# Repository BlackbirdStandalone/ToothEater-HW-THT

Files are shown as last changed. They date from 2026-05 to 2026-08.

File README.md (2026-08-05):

# ToothEater-HW-THT

This repository contains the hardware design of the Honda Blackbird v1.1 Tooth Eater Module - (Through hole version). This through hole version is intended for the DIY'er for easier construction. This PCB is a simple 2 layer design, measuring 44mm x 44mm for insertion into the Hammond 1551R case.<br /><br />
This hardware is designed to work with the latest firmware version (v1.x) contained in the firmware respository. I.e. <i>'ToothEater_v1.2.hex'.</i><br />
<br />
Shown below are blank boards as received by PCBWay. This is a small unit slightly larger than a matchbox, shown in the 2" x 2" case.

<table border="1">
<tr>

<td align="center" valign="center">
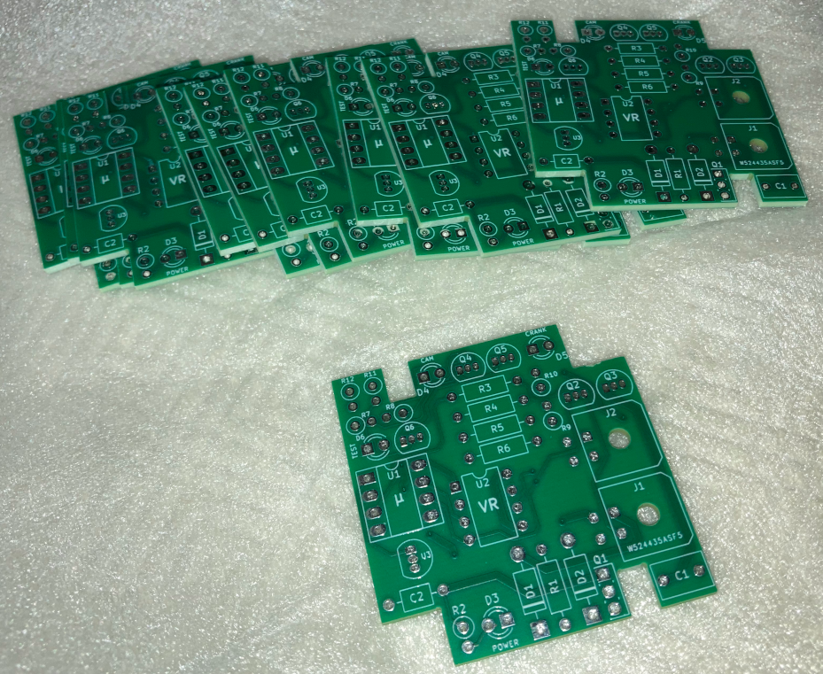
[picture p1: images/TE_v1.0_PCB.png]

</td>

<td>
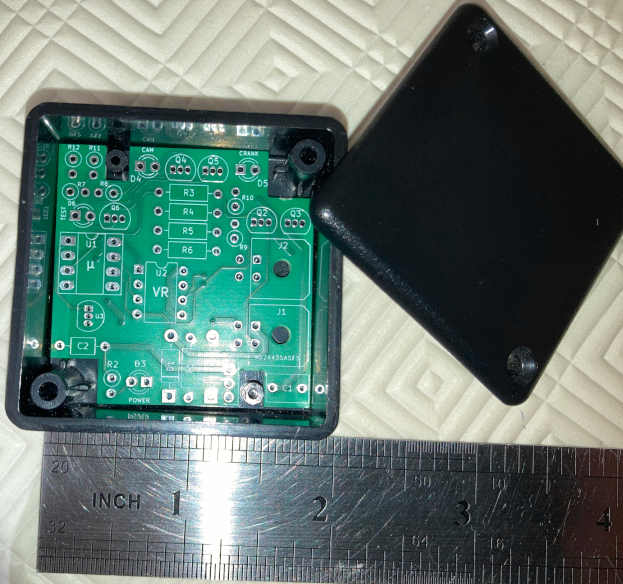
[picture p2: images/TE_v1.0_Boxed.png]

</td>

</tr>
</table>

<br />

A zoomed picture of the board is shown below. The full bill of materials can be found in the 'BOM' directory, however the table below will quickly identify the components. This table reflects the BOM for PCB v1.1.

<table border="3">
<tr>
<td align="center" valign="center"><b><u>Component</u></b></td>
<td align="center" valign="center"><b><u>Value</u></b></td>
</tr>

<tr>
<td align="center" valign="center">U1</td>
<td align="center" valign="center">atTiny85 microcontroller</td>
</tr>

<tr>
<td align="center" valign="center">U2</td>
<td align="center" valign="center">VR conditioner plug-in module (speeduino compatible)</td>
</tr>

<tr>
<td align="center" valign="center">U3</td>
<td align="center" valign="center">MCP100 reset chip</td>
</tr>

<tr>
<td align="center" valign="center">Q1</td>
<td align="center" valign="center">BD681</td>
</tr>

<tr>
<td align="center" valign="center">D1</td>
<td align="center" valign="center">1N4004</td>
</tr>

<tr>
<td align="center" valign="center">D2</td>
<td align="center" valign="center">6.2v zener</td>
</tr>

<tr>
<td align="center" valign="center">C1, C2</td>
<td align="center" valign="center">100n</td>
</tr>

<tr>
<td align="center" valign="center">R1</td>
<td align="center" valign="center">1K5</td>
</tr>

<tr>
<td align="center" valign="center">R2</td>
<td align="center" valign="center">470</td>
</tr>

<tr>
<td align="center" valign="center">R3,R5</td>
<td align="center" valign="center">10K</td>
</tr>

<tr>
<td align="center" valign="center">R4,R6</td>
<td align="center" valign="center">1K</td>
</tr>

<tr>
<td align="center" valign="center">R7,R9</td>
<td align="center" valign="center">47K</td>
</tr>

<tr>
<td align="center" valign="center">R11</td>
<td align="center" valign="center">4K7</td>
</tr>

<tr>
<td align="center" valign="center">R8,R10,R12</td>
<td align="center" valign="center">330</td>
</tr>

<tr>
<td align="center" valign="center">Q2,Q3,Q4,Q5,Q6</td>
<td align="center" valign="center">BC546B</td>
</tr>

<tr>
<td align="center" valign="center">D3</td>
<td align="center" valign="center">Power Led - Red (standard 3mm spacing)</td>
</tr>

<tr>
<td align="center" valign="center">D4,D5</td>
<td align="center" valign="center">Crank and cam Leds - Yellow (standard 3mm spacing)</td>
</tr>

<tr>
<td align="center" valign="center">J1,J2</td>
<td align="center" valign="center">Molex Micro-Fit 3.0 43045 </td>
</tr>

</table>

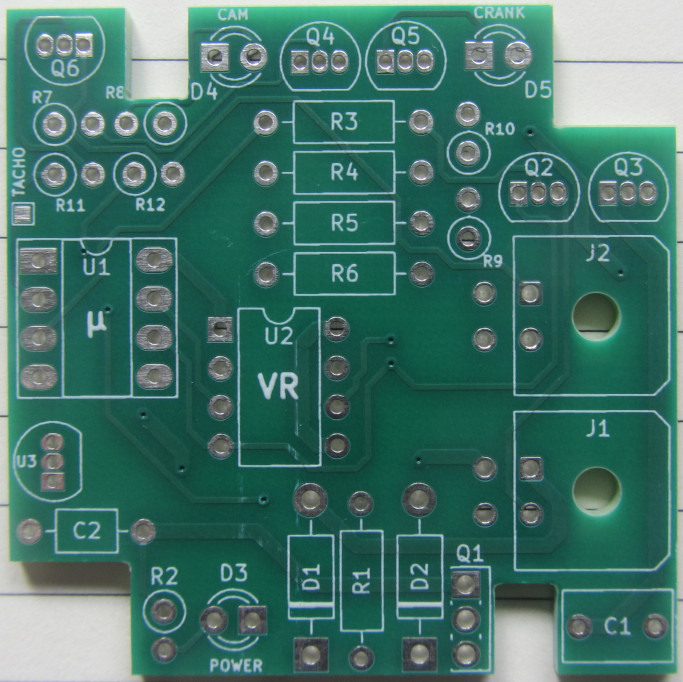
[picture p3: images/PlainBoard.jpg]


<br /><br />
The board is shown below with the components assembled.
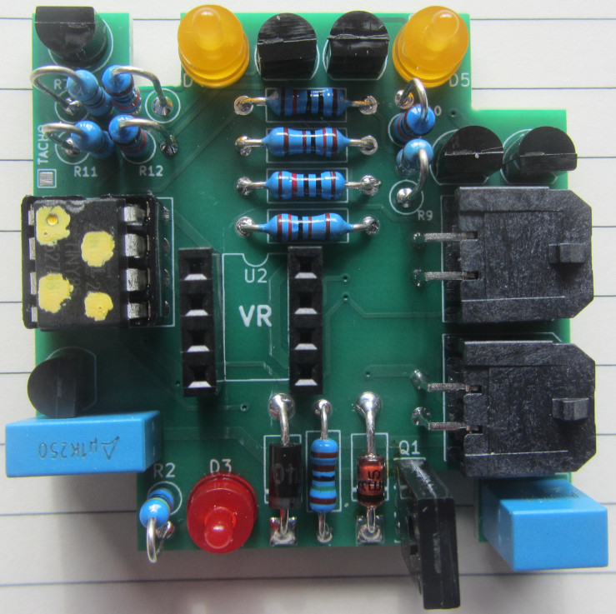
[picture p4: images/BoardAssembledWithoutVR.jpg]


<br />

<table border="1">

The following illustrates different views of the v1.1 assembled board (without the VR mini-board installed).<br />

<tr>
<td align="center" valign="center">
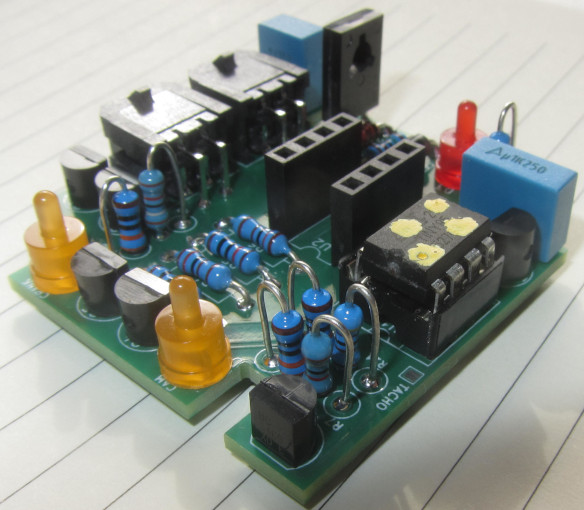
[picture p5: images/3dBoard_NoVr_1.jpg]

</td>
<td>
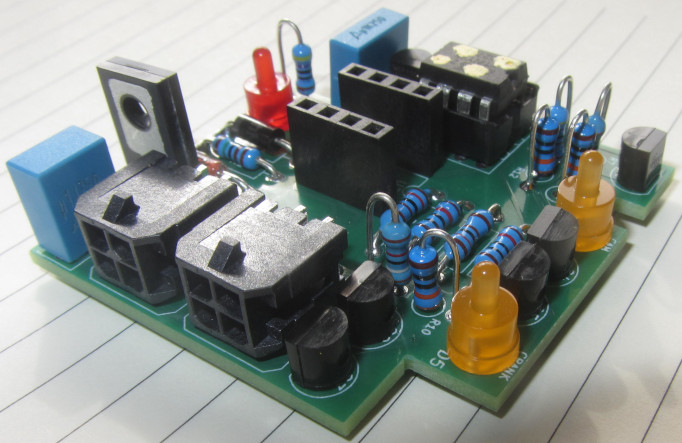
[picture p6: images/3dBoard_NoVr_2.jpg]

</td>
</tr>

<tr>
<td align="center" valign="center">
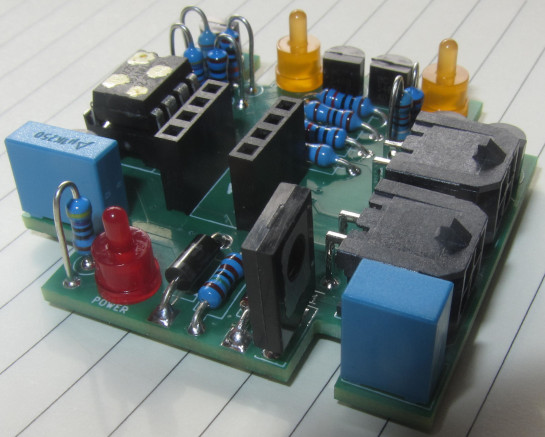
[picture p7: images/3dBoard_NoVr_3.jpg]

</td>
<td>
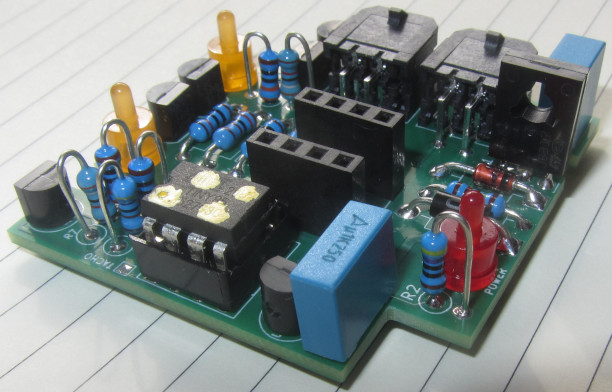
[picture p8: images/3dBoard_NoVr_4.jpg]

</td>
</tr>

</table>

<table border="1">
<tr>

<br /><br />
The board is shown below with two mini wiring harnesses connected to it, along with the speeduino compatible VR plug in mini board.

<td align="center" valign="center">
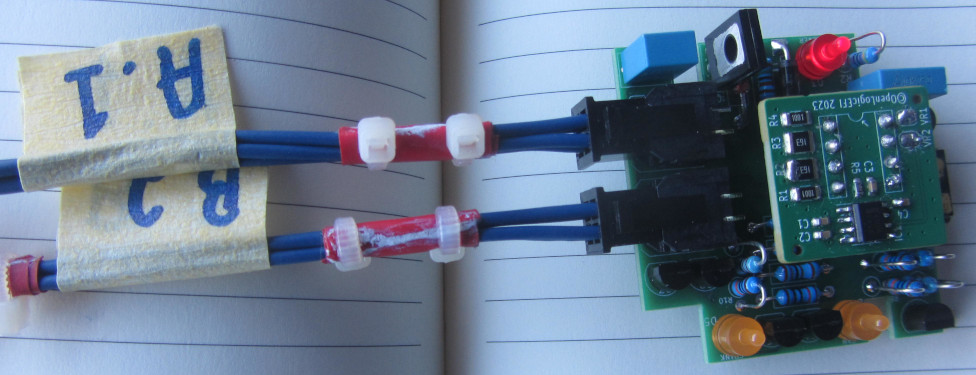
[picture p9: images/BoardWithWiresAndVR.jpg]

</td>

</tr>
</table>

<br /><br />
Once the VR board is inserted into the tooth eater module, it may sit to tall such that it will not allow the lid to close on the case. This is due to the height of the two female 4x1 headers (8.5mm height) that is sits within. To remedy this, the plastic stand-offs may be pryed off with a screwdriver or similar. This will allow the VR module to sink lower into the tooth eater board once it is inserted.

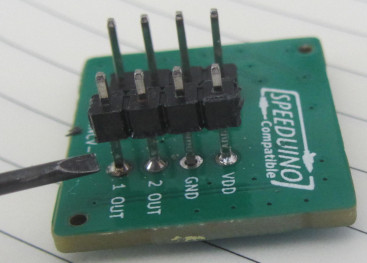
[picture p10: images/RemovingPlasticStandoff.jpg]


<br />
Afterwards it will sit as follows. The overall height will now allow the package to fit within the case.

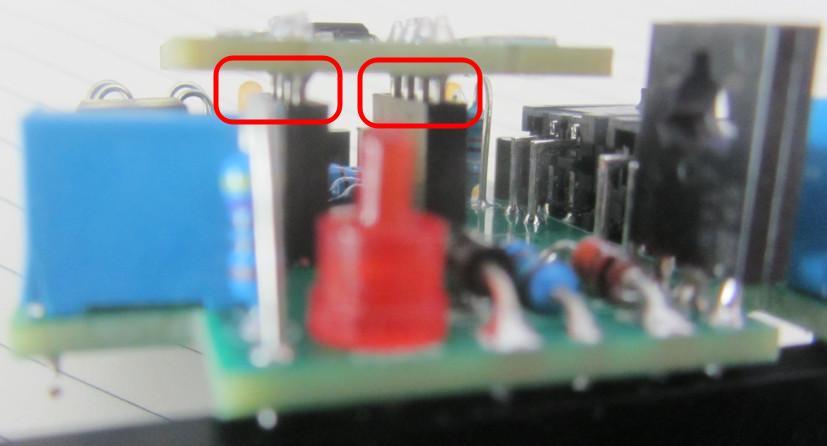
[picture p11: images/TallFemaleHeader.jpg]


<br /><br />
When assembled, the BD681 transistor sits slightly proud of the case top (~2mm). This can be fixed by bending it to the left as shown.

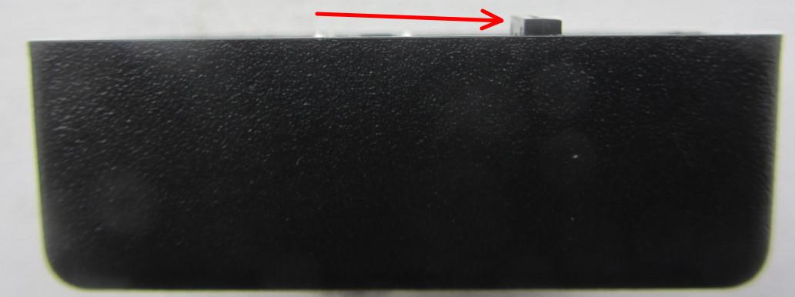
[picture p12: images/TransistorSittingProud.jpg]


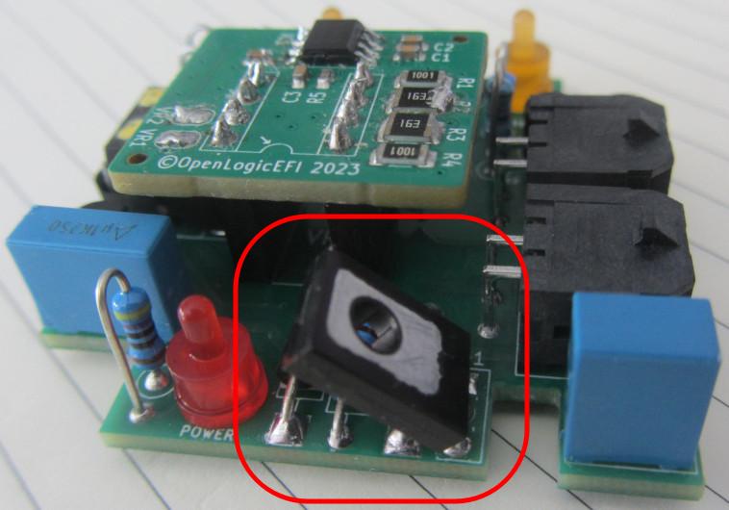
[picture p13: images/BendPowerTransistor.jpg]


<br /><br />
The connectors require a section to be cut out of the case.
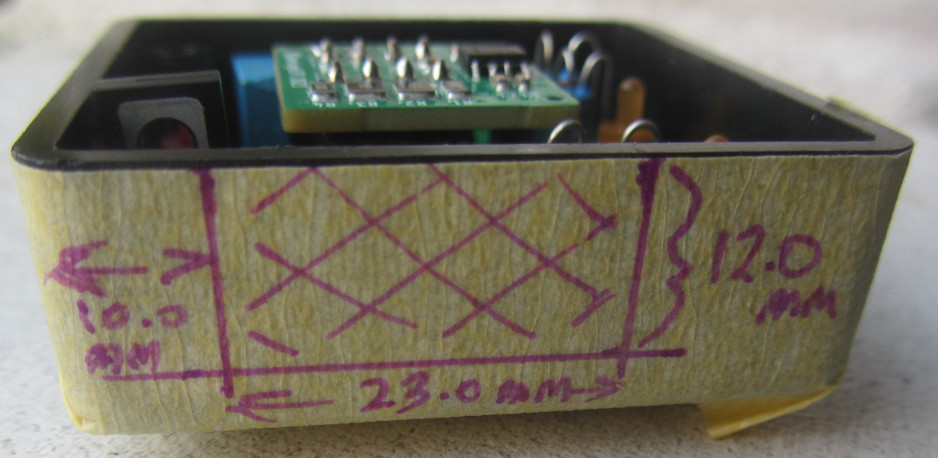
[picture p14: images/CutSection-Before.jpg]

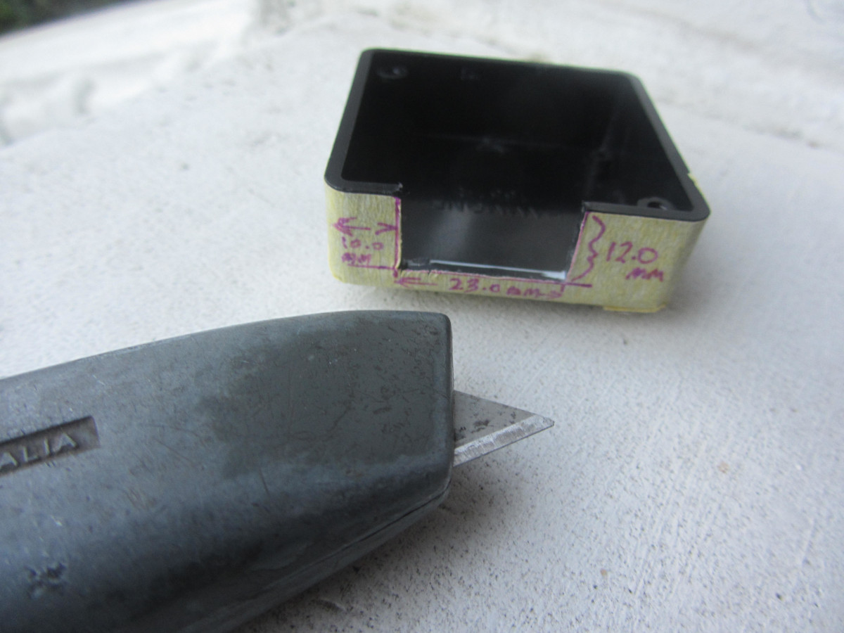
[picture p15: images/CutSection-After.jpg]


<br /><br />
The board is fitted to the case and relative size is shown.

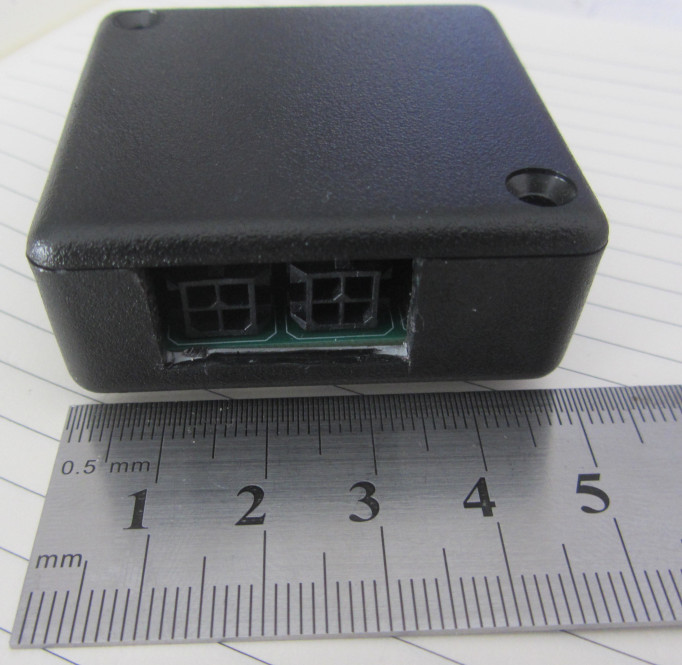
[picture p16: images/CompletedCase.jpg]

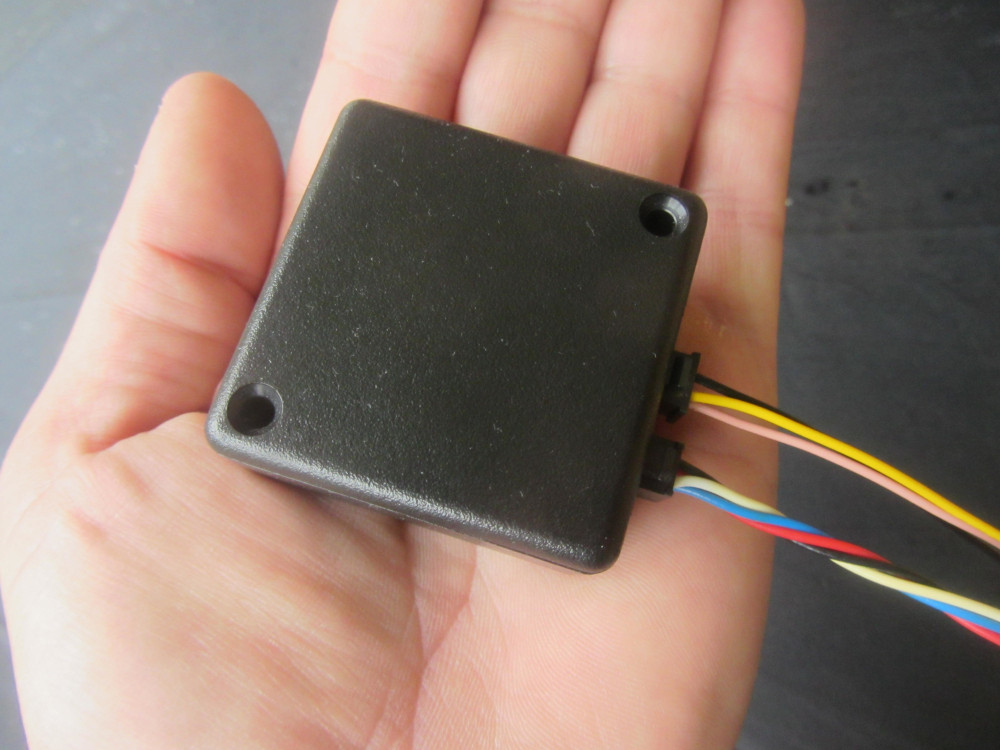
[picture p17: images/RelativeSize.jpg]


<br /><br />

<table border="3">
<tr>
<td>
<p style="text-align: left;">The final connections are shown as follows:</p>
</td>
</tr>

<tr>
<td>
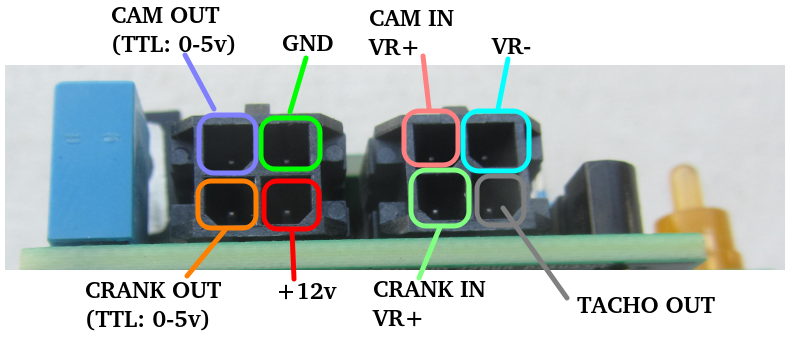
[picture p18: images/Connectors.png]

</td>
</tr>

<tr>
<td>
<p>The board requires +12v and a ground connection. These can be tapped off the wires that feed your ECU.</p>
</td>
</tr>

<tr>
<td>
The inputs to this module are:
<ul>
  <li> CRANK VR+ (from the bikes wiring harness) </li>
  <li> CAM VR+ (from the bikes wiring harness) </li>
  <li> VR- (shared with both crank & cam VR- on the bikes wiring harness) </li>
</ul>
</td>
</tr>

<tr>
<td>
The outputs are:
<ul>
  <li>CAM TTL (0-4.1v level single cam pulse - fed into your downstream ECU)</li>
  <li>CRANK TTL (0-4.1v level single crank pulse - fed into your downstream ECU)</li>
  <li>TACHO (0-12v level square wave - fed to your dash via pin A19 on main wiring harness)</li>
</ul>
</td>
</tr>

<tr>
<td>
<p>Notes:<br />
1. The crank signal is the 12 pulses per crank rotation. The cam signal is post-processed by the tooth eater, therefore 1 cam pulse per engine cycle (I.e. Two crank revolutions, 720 deg).<br /><br />
2. The TTL output voltages are square wave outputs. The output voltage is slightly less than 5.0v and realistically closer to 4.1v. This should be fine in practice for ECUs expecting either 5.0v or 3.3v inputs (with internal built in protection on its inputs). In the future on the next board revision, I may add a jumper and a voltage divider to offer both use cases.<br />
</p>
</td>
</tr>

</table>

<br />

## Additional notes to observe

1. If you are using the speeduino compatible VR conditioner mini board by 'OpenLogic EFI', then you will need to solder both VR1 and VR2 jumpers as shown in the image below. This is so your crank and cam signals can be processed by the tooth eater.
2. There are also additional jumpers on the underside of the board. If you are using the VR board as mentioned above then leave these open circuit (o.c) as they are. These jumpers are of no practial use on the bike. <br />
The purpose of these jumpers are mainly for bench testing the board with 0-5v TTL signals when testing with ardu-stim, so they should only be soldered when bench testing or when HALL effect sensors are being used instead of the VR.
<table border="1">
<tr>

<td align="center" valign="center">
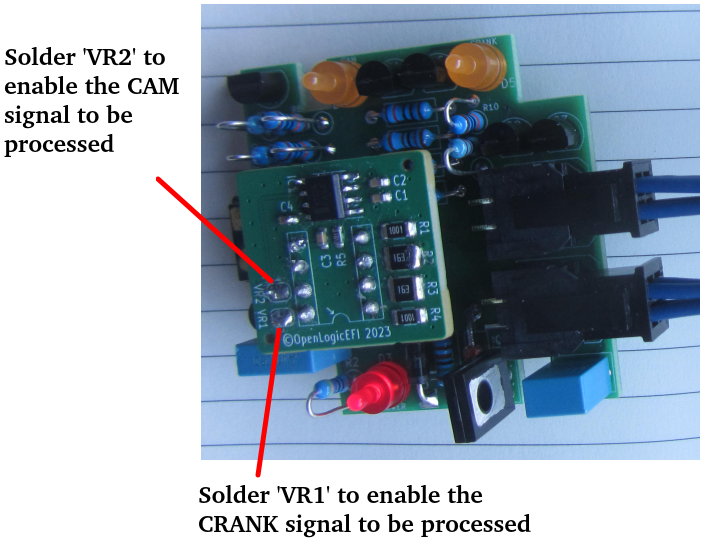
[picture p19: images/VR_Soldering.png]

</td>

<td>
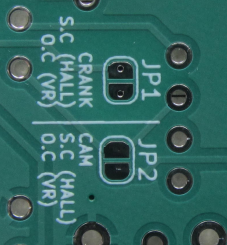
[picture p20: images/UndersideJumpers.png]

</td>

</tr>
</table>

<br /><br />

# Hardware Design

<table border="1">

<tr> 
<td width="20%">
<strong><u>Current Revision</u></strong>
</td>
<td width="60%">
<strong><u>Date</u></strong>
</td>
<td width="20%">
<strong><u>Author</u></strong>
</td>
</tr>

<tr>
<td width="20%">
v1.1
</td>
<td width="60%">
July 2026
</td>
<td width="20%">
Alex Kiaos
</td>
</tr>

</table>

<br />
This project has been designed in Kicad 6.0.11 under linux and is licenced under the CERN Open Hardware Licence Version 2 - Strongly Reciprocal (CERN-OHL-S).<br /><br />

The directory structure of this project is as follows:

<p id=directories>
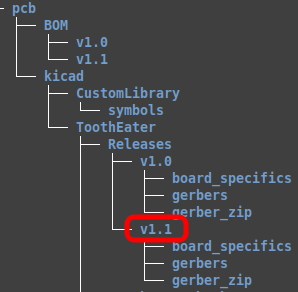
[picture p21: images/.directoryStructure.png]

</p>

<table border="1">

<tr> 
<td width="20%">
<strong><u>Directory</u></strong>
</td>
<td width="80%">
<strong><u>Description</u></strong>
</td>
</tr>

<tr>
<td width="20%">
BOM
</td>
<td width="80%">
Bill of materials
</td>
</tr>

<tr>
<td width="20%">
kicad
</td>
<td width="80%">
The main project file is 'ToothEater.kicad_pro' found under</br>'/pcb/kicad/ToothEater'.</br></br>
Gerber files can be found as a group of 9 individual files under the 'gerbers' directory or as a single zipped file under the 'gerber_zipped' directory for uploading to a PCB house for manufacture.</br></br>
The 'CustomLibrary' directory contains the custom symbols and footprints used in the project.
</td>
</tr>

</table>

</br>
After cloning the repository and opening the project for the first time, you may need to set up the symbol library path.<br />

To setup the symbols library, in the menu:<br>
<pre><i>Preferences -> Manage Symbol Libraries</i><br>
  Then in the 2nd tab under 'Project specific libraries' add the following:<br>
Nickname: <b>ToothEater</b><br>
Library Path: <b>${KIPRJMOD}/../CustomLibrary/symbols/ToothEater_symbols.kicad_sym</b><br>
</pre>
<br><br>

# Relevant links

### PCBWay
To visit the PCBWay project and/or place an [order](https://www.pcbway.com/project/shareproject/Honda_CBR_Tooth_Eater_Module_Compatibility_module_for_the_CBR_1100XX_Super_Bla_bf3a4c0d.html).

### Wiring Harness & Pinouts
To see the ECU pin-out details, refer to the latest pdf file at: 
[Wiring Harness Pinout diagram](https://github.com/BlackbirdStandalone/Documentation/tree/main/wiring).

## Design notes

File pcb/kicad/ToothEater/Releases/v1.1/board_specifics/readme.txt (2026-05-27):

Gerber files for pcbway were generated using the suggestions from this link
https://www.pcbway.com/blog/help_center/Generate_Gerber_file_from_Kicad.html

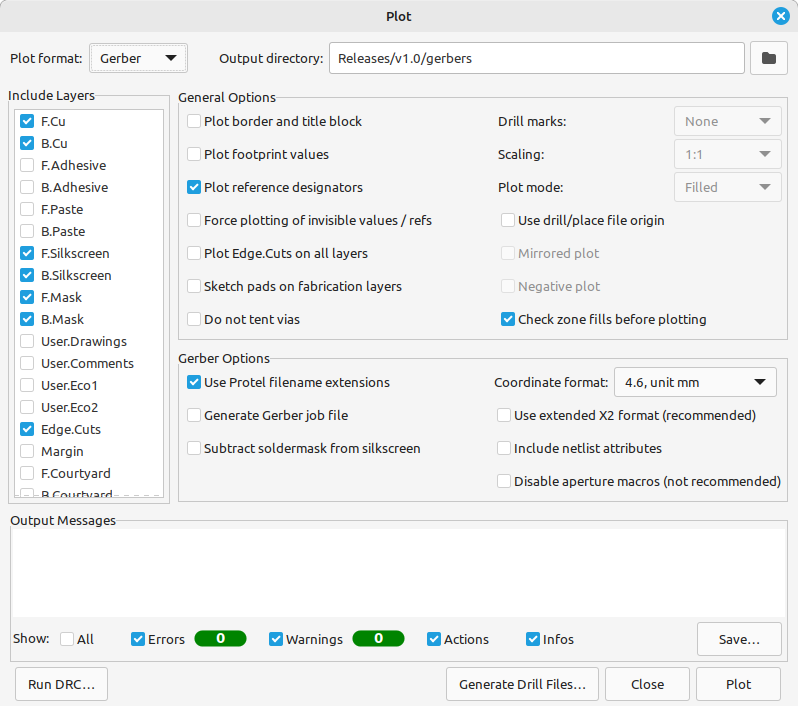
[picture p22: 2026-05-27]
pcb/kicad/ToothEater/Releases/v1.1/board_specifics/Pcbway_gerber_config.png

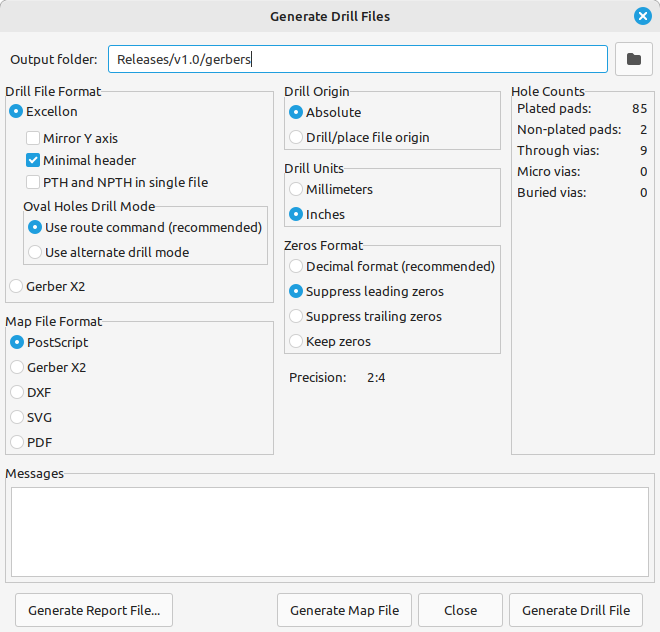
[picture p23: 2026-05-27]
pcb/kicad/ToothEater/Releases/v1.1/board_specifics/Pcbway_drill_config.png

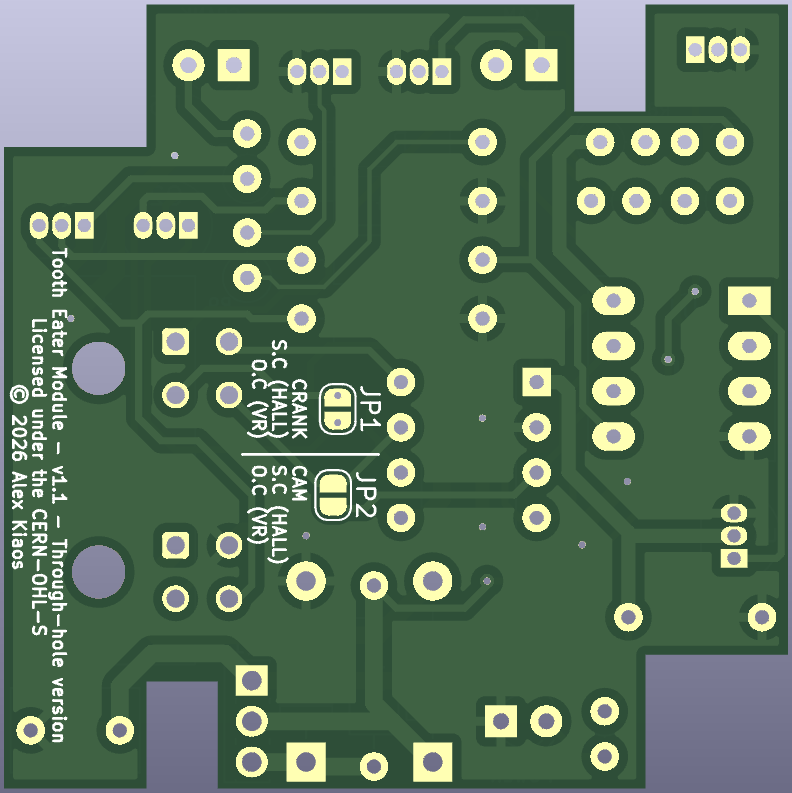
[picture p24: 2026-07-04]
pcb/kicad/ToothEater/Releases/v1.1/board_specifics/BottomSide.png

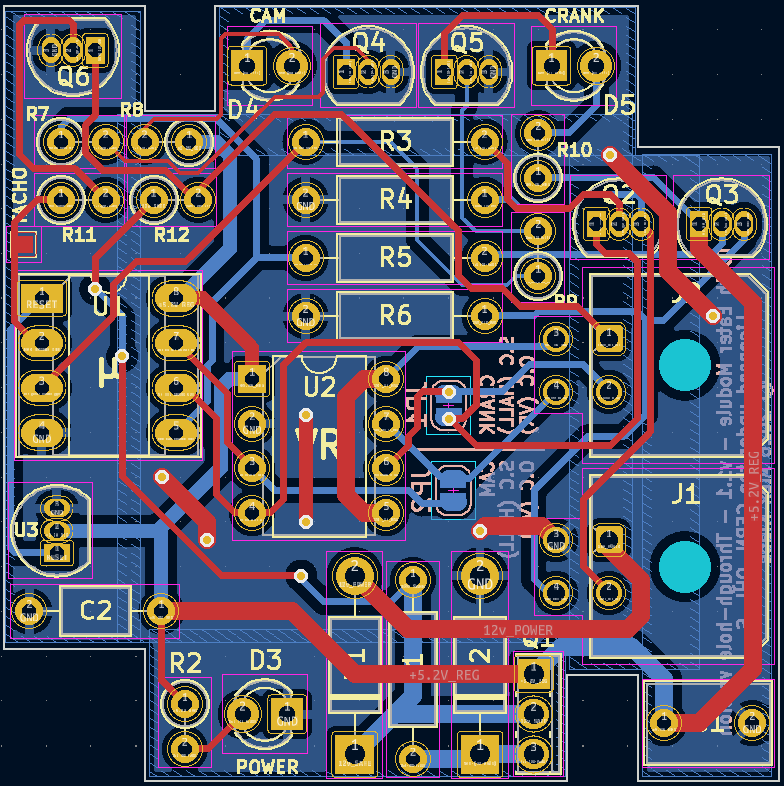
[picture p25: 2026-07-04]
pcb/kicad/ToothEater/Releases/v1.1/board_specifics/PcbLayout.png

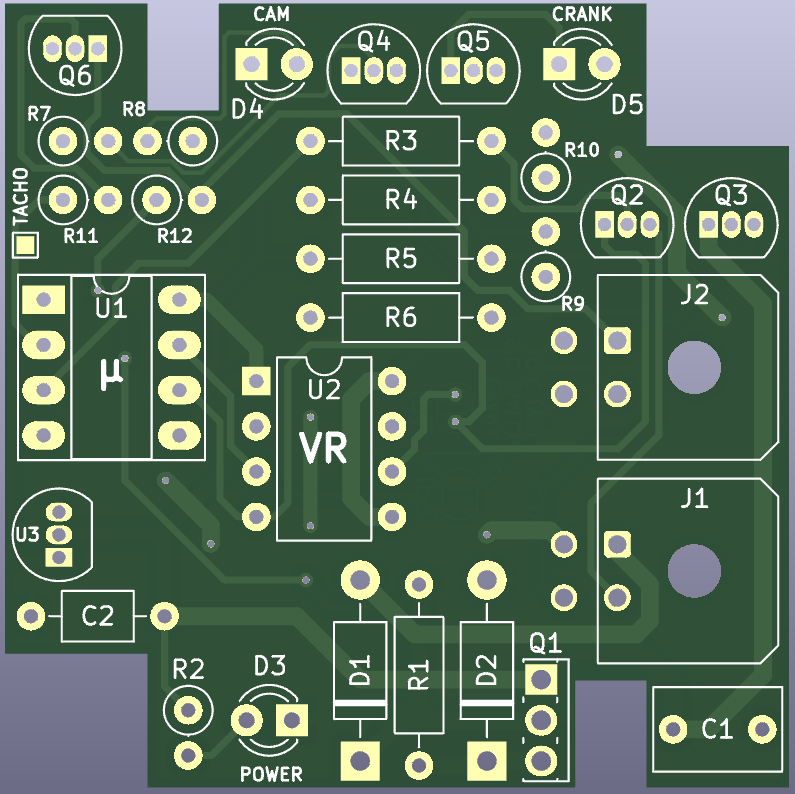
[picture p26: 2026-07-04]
pcb/kicad/ToothEater/Releases/v1.1/board_specifics/TopSide.png

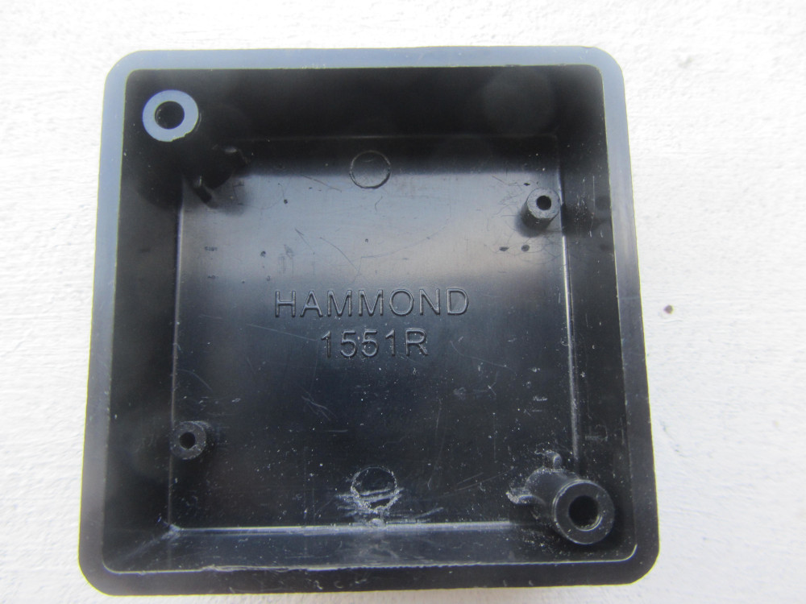
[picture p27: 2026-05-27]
images/Case_Hammond_1551R.jpg

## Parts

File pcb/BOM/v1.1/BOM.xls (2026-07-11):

Designator | Quantity | Value | Type | Kicad Footprint | Category On Board | OEM PART | DigiKey Part No | Series | Description | Link
U1 | 1 |  |  | DIP-8_W7.62mm_Socket_LongPads | AtTiny85 - 20Mhz Chip | ATTINY85-20PU | ATTINY85-20PU-ND | AVR® Attiny, Functional Safety (FuSa) | IC MCU 8BIT 8KB FLASH 8DIP | https://www.digikey.com.au/en/products/detail/microchip-technology/ATTINY85-20PU/735469
U1 | 1 |  |  | - | AtTiny85 - 8 pin DIP socket | A 08-LC-TT | AE9986-ND | - | CONN IC DIP SOCKET 8POS TIN | https://www.digikey.com.au/en/products/detail/assmann-wsw-components/A-08-LC-TT/821740
U2 | 2 |  |  | - | VR Header Stand-off | SSK02-FPH-254-A4 | 2223-SSK02-FPH-254-A4-ND | - | 2.54MM FEMALE HEADER 1X4PIN, Y T | https://www.digikey.com.au/en/products/detail/same-sky-formerly-cui-devices/SSK02-FPH-254-A4/28772197
U3 | 1 |  |  | TO-92_Inline | AtTiny85 - Reset chip (MCP 100) | MCP100-475DI/TO | MCP100-475DI/TO-ND | - | IC SUPERVISOR 1 CHANNEL TO92-3 | https://www.digikey.com.au/en/products/detail/microchip-technology/mcp100-475di-to/275213
C2 | 1 | 100n | Film Cap | C_Axial_L3.8mm_D2.6mm_P7.50mm_Horizontal | AtTiny85 - Reset capacitor (0.1uF) | B32520C3104K000 | 495-2426-ND | - | CAP FILM 0.1UF 10% 250VDC RADIAL | https://www.digikey.com.au/en/products/detail/epcos-tdk-electronics/B32520C3104K000/1089706
D1 | 1 | 1N4004 |  | D_DO-41_SOD81_P10.16mm_Horizontal | 12v to 5v circuit - (1N4004) | 1N4004-G | 641-1311-1-ND | - | DIODE STANDARD 400V 1A DO41 | https://www.digikey.com.au/en/products/detail/comchip-technology/1N4004-G/1979655
D2 | 1 | 6.2v |  | D_DO-41_SOD81_P10.16mm_Horizontal | 12v to 5v circuit - (6.2v Zener) | 1N4735A | 1N4735AFS-ND | - | DIODE ZENER 6.2V 1W DO41 | https://www.digikey.com.au/en/products/detail/onsemi/1N4735A/977220
C1 | 1 | 100n | Film Cap | C_Rect_L7.0mm_W4.5mm_P5.00mm | 12v to 5v circuit - (100n cap) | B32529C3104J189 | 495-B32529C3104J189TR-ND | B3252* - MKT General Purpose | CAP FILM 0.1UF 5% 250VDC RADIAL | https://www.digikey.com.au/en/products/detail/epcos-tdk-electronics/B32529C3104J189/1089810
Q1 | 1 |  |  | SIPAK_Vertical | 12v to 5v circuit - (BD681 transistor) | BD681 | 497-7177-5-ND | - | TRANS NPN DARL 100V 4A SOT-32-3 | https://www.digikey.com.au/en/products/detail/stmicroelectronics/BD681/1037697
R1 | 1 | 1K5 |  | R_Axial_DIN0207_L6.3mm_D2.5mm_P10.16mm_Horizontal | Resistor 1.5K (1/4W - 1%) | MFR-25FRF52-1K5 | 13-MFR-25FRF52-1K5TR-ND | - | RES 1.5K OHM 1% 1/4W AXIAL
R2 | 1 | 470 |  | R_Axial_DIN0207_L6.3mm_D2.5mm_P2.54mm_Vertical | Resistor 470R (1/4W - 1%) | MFR-25FRF52-470R | 13-MFR-25FRF52-470RTR-ND | - | RES 470 OHM 1% 1/4W AXIAL
R3,R5 | 2 | 10k |  | R_Axial_DIN0207_L6.3mm_D2.5mm_P10.16mm_Horizontal | Resistor 10K (1/4W - 1%) | MFR-25FRF52-10K | 13-MFR-25FRF52-10KTR-ND | - | RES 10K OHM 1% 1/4W AXIAL | https://www.digikey.com.au/en/products/detail/yageo/MFR-25FRF52-10K/14626
R4,R6 | 2 | 1k |  | R_Axial_DIN0207_L6.3mm_D2.5mm_P10.16mm_Horizontal | Resistor 1K (1/4W - 1%) | MFR-25FRF52-1K | 13-MFR-25FRF52-1KTR-ND | - | RES 1K OHM 1% 1/4W AXIAL
R7,R9 | 2 | 47k |  | R_Axial_DIN0207_L6.3mm_D2.5mm_P2.54mm_Vertical | Resistor 47K (1/4W - 1%) | MFR-25FRF52-47K | 13-MFR-25FRF52-47KTR-ND | - | RES 47K OHM 1% 1/4W AXIAL
R11 | 1 | 4k7 |  | R_Axial_DIN0207_L6.3mm_D2.5mm_P2.54mm_Vertical | Resistor 4K7 (1/4W - 1%) | MFR-25FRF52-4K7 | 13-MFR-25FRF52-4K7TR-ND |  | RES 4.7K OHM 1% 1/4W AXIAL
R8,R10,R12 | 3 | 330 |  | R_Axial_DIN0207_L6.3mm_D2.5mm_P2.54mm_Vertical | Resistor 330R (1/4W - 1%) | MFR-25FRF52-330R | 13-MFR-25FRF52-330RTR-ND | - | RES 330 OHM 1% 1/4W AXIAL
Q2,Q3,Q4,Q5,Q6 | 5 |  |  | TO-92_Inline | Transistors - General (BC546) | BC546B | 4878-BC546BCT-ND | - | TRANS NPN 65V 0.1A TO-92 | https://www.digikey.com.au/en/products/detail/diotec-semiconductor/BC546B/13164482
D3, D4, D5 | 3 |  |  | LED_D3.0mm_IRBlack | Leds | 151051RS11000 | 732-5016-ND | - | LED RED DIFFUSED 5MM ROUND T/H | https://www.digikey.com.au/en/products/detail/w%C3%BCrth-elektronik/151051RS11000/4490012
J1,J2 | 2 |  |  | Molex_Micro-Fit_3.0_43045-0400_2x02_P3.00mm_Horizontal | PLUG | 0430450400 (MOLEX) | WM1814-ND | Micro-Fit 3.0 43045 | CONN HEADER R/A 4POS 3MM | https://www.digikey.com.au/en/products/detail/molex/0430450400/252527
External to board (plugs, pins & case)
 | 2 |  |  | - | Receptacle | 0430250400 (MOLEX) | WM1784-ND | Micro-Fit 3.0 43025 | CONN RCPT HSG 4POS 3.00MM | https://www.digikey.com.au/en/products/detail/molex/0430250400/252497
 | 7 |  |  | - | Pin (20-24 AWG) | 0430300001 (MOLEX) | WM1837TR-ND | Micro-Fit 3.0 43030 | CONN SOCKET 20-24AWG CRIMP TIN | https://www.digikey.com.au/en/products/detail/molex/0430300001/467796
 | 1 |  |  | - | Box enclosure (Hammond) | 1551RBK | HM913-ND | 1551 | BOX ABS BLACK 1.97"L X 1.97"W | https://www.digikey.com.au/en/products/detail/hammond-manufacturing/1551RBK/1090725
Also, a dual VR conditioner circuit board must be separately installed into the Tooth Eater board. I.e. Speeduino compatible VR plug in module (can be purchased online).
Eg.
https://openlogicefi.com/shop/p/duel-vr-conditioner-detonationems

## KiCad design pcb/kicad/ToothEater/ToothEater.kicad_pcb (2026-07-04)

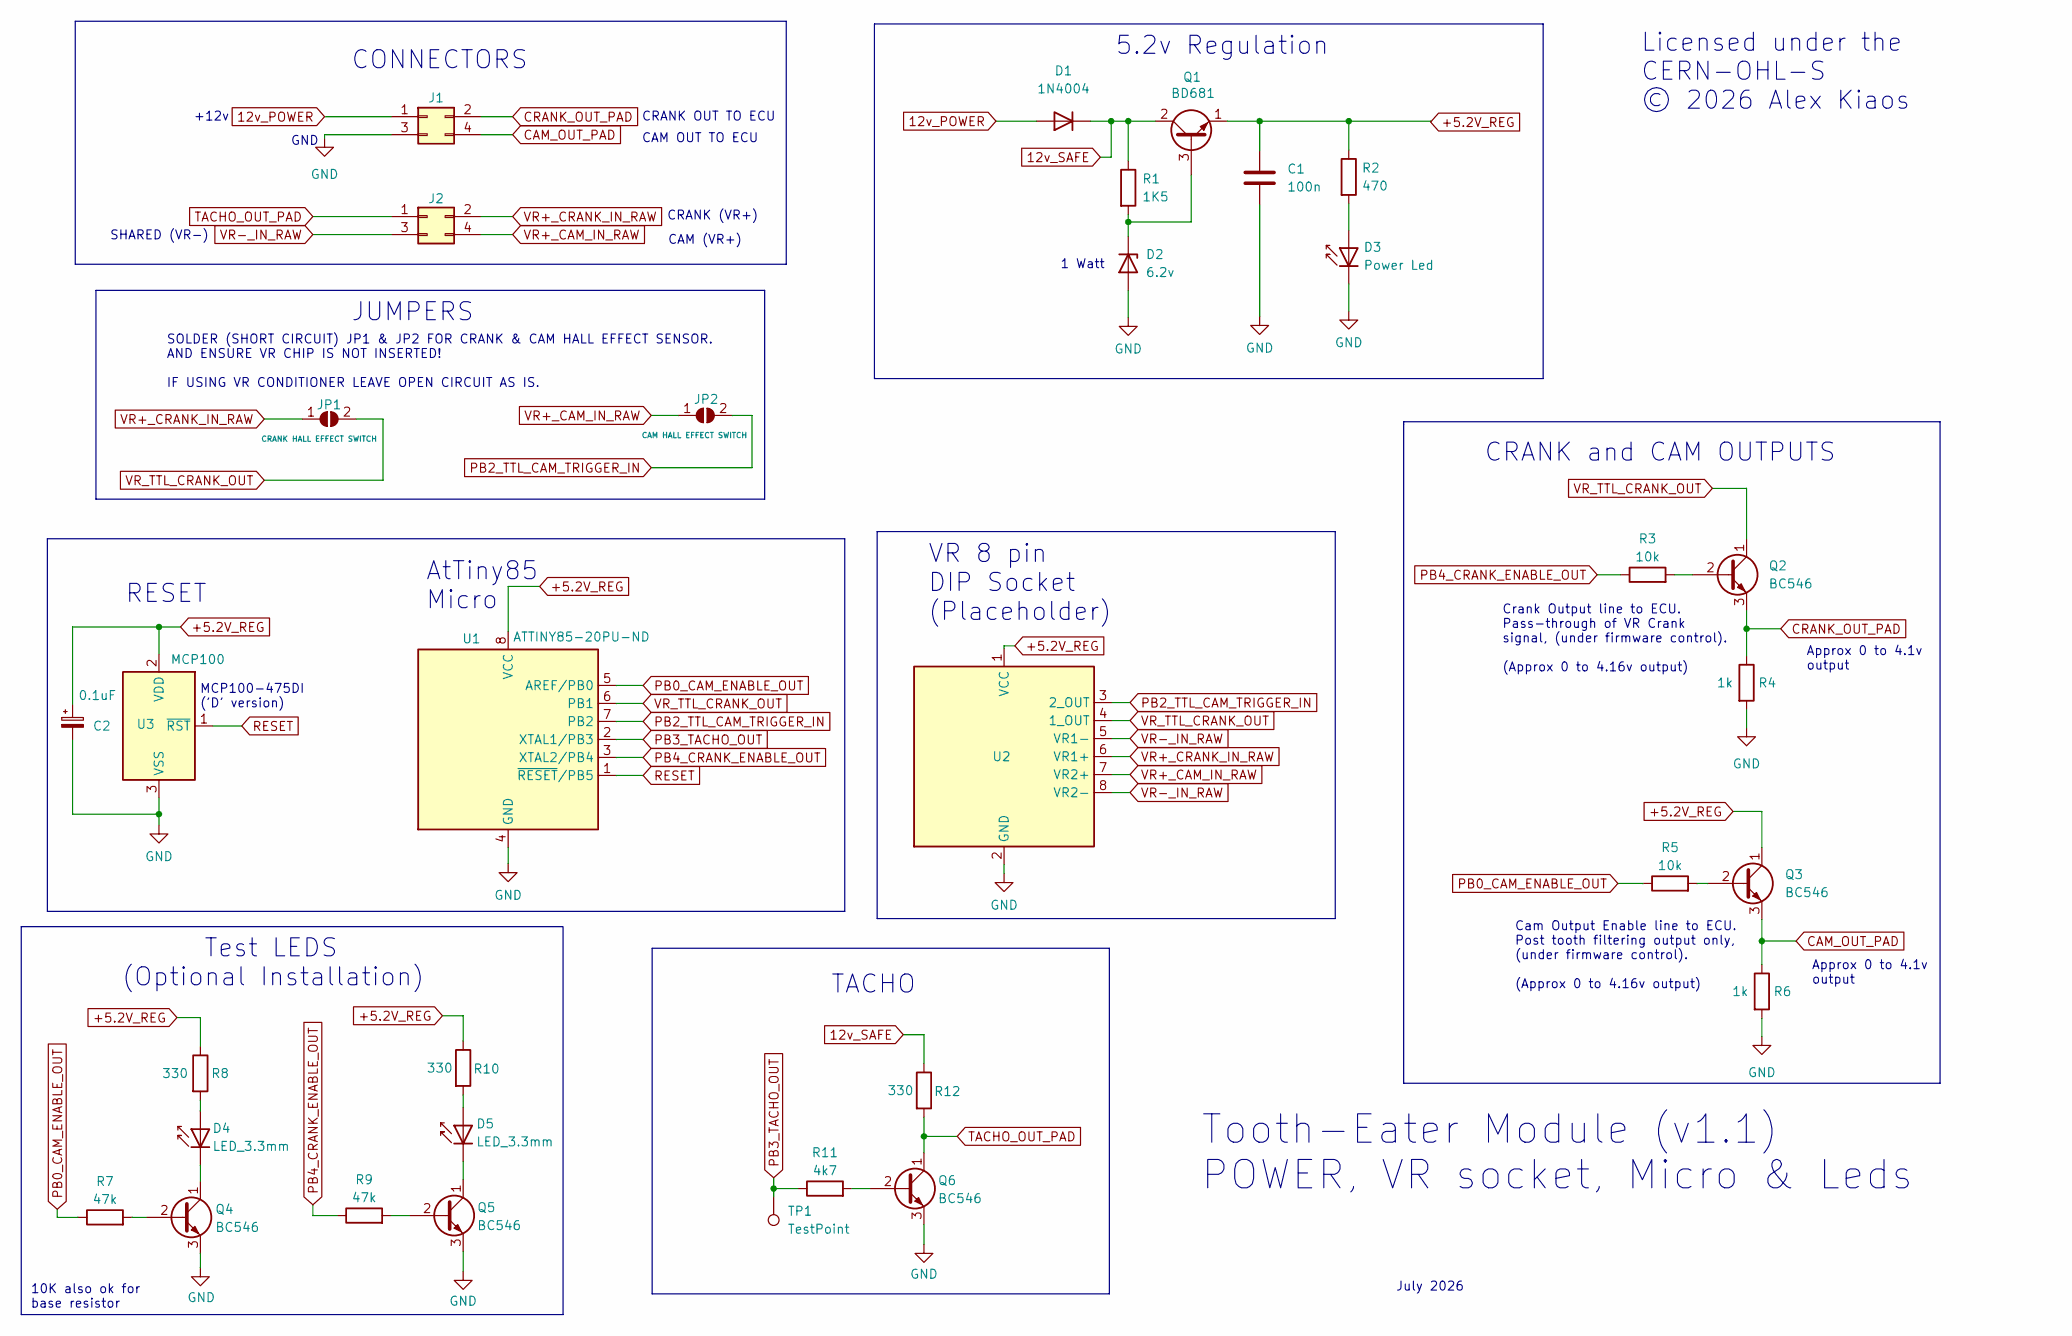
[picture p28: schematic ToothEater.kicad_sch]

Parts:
C1: 100n; C_Rect_L7.0mm_W4.5mm_P5.00mm
C2: 0.1uF; C_Axial_L3.8mm_D2.6mm_P7.50mm_Horizontal
D1: 1N4004; D_DO-41_SOD81_P10.16mm_Horizontal
D2: 6.2v; D_DO-41_SOD81_P10.16mm_Horizontal
D3: Power Led; LED_D3.0mm_IRBlack
D4, D5: LED_3.3mm; LED_D3.0mm_IRBlack
J1, J2: Conn_02x02_Molex; Molex_Micro-Fit_3.0_43045-0400_2x02_P3.00mm_Horizontal
JP1: CRANK HALL EFFECT SWITCH; SolderJumper-2_P1.3mm_Open_RoundedPad1.0x1.5mm
JP2: CAM HALL EFFECT SWITCH; SolderJumper-2_P1.3mm_Open_RoundedPad1.0x1.5mm
Q1: BD681; SIPAK_Vertical
Q2, Q3, Q4, Q5, Q6: BC546; TO-92_Inline
R1: 1K5; R_Axial_DIN0207_L6.3mm_D2.5mm_P10.16mm_Horizontal
R2: 470; R_Axial_DIN0207_L6.3mm_D2.5mm_P2.54mm_Vertical
R3, R5: 10k; R_Axial_DIN0207_L6.3mm_D2.5mm_P10.16mm_Horizontal
R4, R6: 1k; R_Axial_DIN0207_L6.3mm_D2.5mm_P10.16mm_Horizontal
R7, R9: 47k; R_Axial_DIN0207_L6.3mm_D2.5mm_P2.54mm_Vertical
R8, R10, R12: 330; R_Axial_DIN0207_L6.3mm_D2.5mm_P2.54mm_Vertical
R11: 4k7; R_Axial_DIN0207_L6.3mm_D2.5mm_P2.54mm_Vertical
TP1: TestPoint; TestPoint_Pad_1.0x1.0mm
U1: ATTINY85-20PU-ND; DIP-8_W7.62mm_Socket_LongPads
U2: VR_Conditioner_8-Pin-DIP; DIP-8_W7.62mm
U3: MCP100; TO-92_Inline

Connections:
12v_POWER: D1.2 (A), J1.1
12v_SAFE: D1.1 (K), Q1.2 (C), R1.1, R12.1
+5.2V_REG: C1.1, C2.1, Q1.1 (E), Q3.1 (C), R2.1, R8.1, R10.1, U1.8 (VCC), U2.1 (VCC), U3.2 (VDD)
CAM_OUT_PAD: J1.4, Q3.3 (E), R6.1
CRANK_OUT_PAD: J1.2, Q2.3 (E), R4.1
GND: C1.2, C2.2, D2.2 (A), D3.1 (K), J1.3, Q4.3 (E), Q5.3 (E), Q6.3 (E), R4.2, R6.2, U1.4 (GND), U2.2 (GND), U3.3 (VSS)
unnamed: D2.1 (K), Q1.3 (B), R1.2
unnamed: D3.2 (A), R2.2
unnamed: D4.1 (K), Q4.1 (C)
unnamed: D4.2 (A), R8.2
unnamed: D5.1 (K), Q5.1 (C)
unnamed: D5.2 (A), R10.2
unnamed: Q2.2 (B), R3.2
unnamed: Q3.2 (B), R5.2
unnamed: Q4.2 (B), R7.2
unnamed: Q5.2 (B), R9.2
unnamed: Q6.2 (B), R11.2
PB0_CAM_ENABLE_OUT: R5.1, R7.1, U1.5 (AREF/PB0)
PB2_TTL_CAM_TRIGGER_IN: JP2.2 (B), U1.7 (PB2), U2.3 (2_OUT)
PB3_TACHO_OUT: R11.1, TP1.1, U1.2 (XTAL1/PB3)
PB4_CRANK_ENABLE_OUT: R3.1, R9.1, U1.3 (XTAL2/PB4)
RESET: U1.1 (~RESET/PB5), U3.1 (~RST)
TACHO_OUT_PAD: J2.1, Q6.1 (C), R12.2
VR+_CAM_IN_RAW: J2.4, JP2.1 (A), U2.7 (VR2+)
VR+_CRANK_IN_RAW: J2.2, JP1.1 (A), U2.6 (VR1+)
VR-_IN_RAW: J2.3, U2.5 (VR1-), U2.8 (VR2-)
VR_TTL_CRANK_OUT: JP1.2 (B), Q2.1 (C), U1.6 (PB1), U2.4 (1_OUT)

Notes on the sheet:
CAM OUT TO ECU
CAM (VR+)
Licensed under the CERN-OHL-S © 2026 Alex Kiaos
+12v
CRANK (VR+)
Approx 0 to 4.1v output
VR 8 pin DIP Socket (Placeholder)
GND
CRANK and CAM OUTPUTS
5.2v Regulation
Tooth-Eater Module (v1.1) POWER, VR socket, Micro & Leds
Crank Output line to ECU. Pass-through of VR Crank signal, (under firmware control). (Approx 0 to 4.16v output)
TACHO
CRANK OUT TO ECU
1 Watt
SOLDER (SHORT CIRCUIT) JP1 & JP2 FOR CRANK & CAM HALL EFFECT SENSOR. AND ENSURE VR CHIP IS NOT INSERTED! IF USING VR CONDITIONER LEAVE OPEN CIRCUIT AS IS.
10K also ok for base resistor
Cam Output Enable line to ECU. Post tooth filtering output only, (under firmware control). (Approx 0 to 4.16v output)
July 2026
JUMPERS
CONNECTORS
AtTiny85 Micro
SHARED (VR-)
Test LEDS (Optional Installation)
MCP100-475DI ('D' version)
RESET

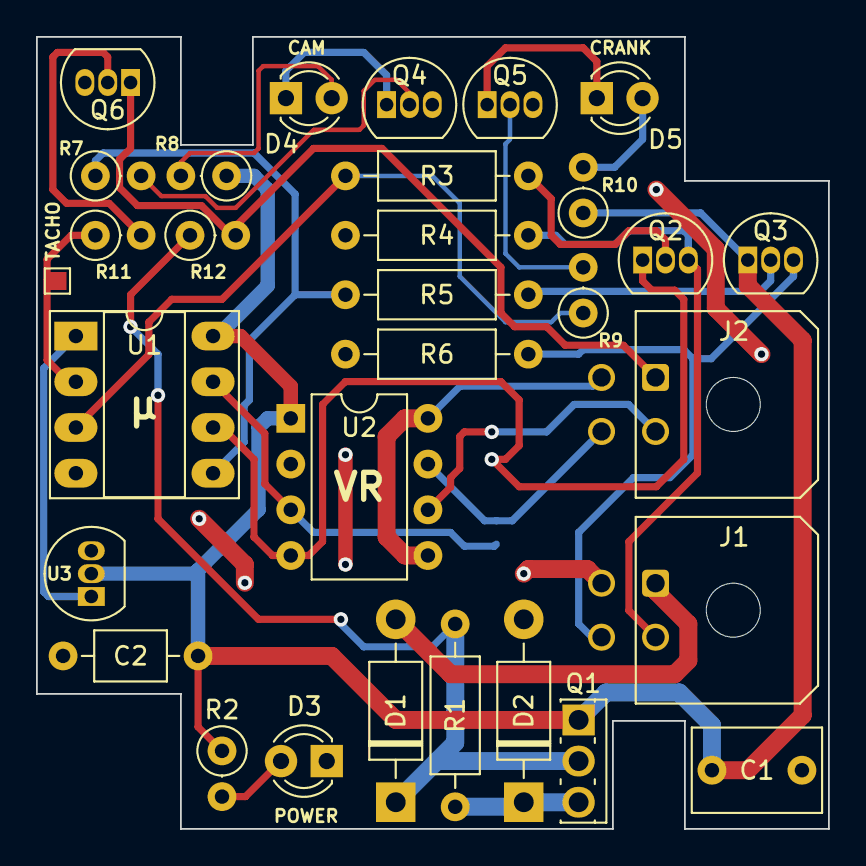
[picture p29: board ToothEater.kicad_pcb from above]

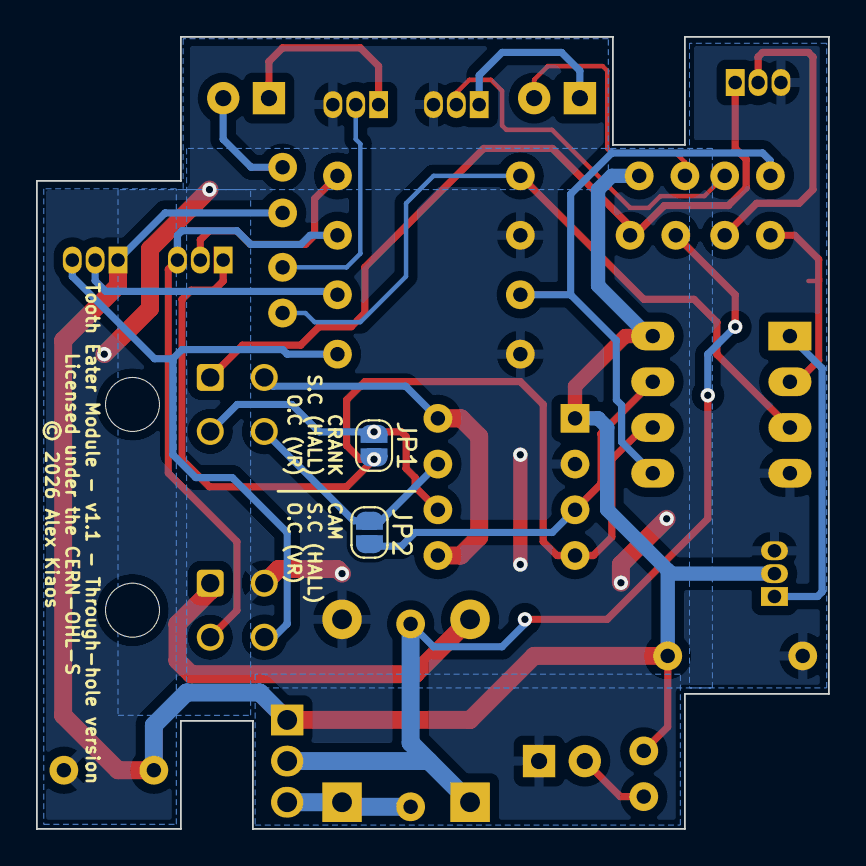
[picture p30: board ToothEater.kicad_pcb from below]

Board: 2 copper layers, 44.0 x 44.0 mm, 33 parts (2 on the bottom side), 27 nets.

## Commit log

2026-05-27 - PCB
    [BOM.xls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]
2026-07-03 - PCB v1.1 preparation.
    [ToothEater.kicad_pcb, ToothEater.kicad_sch]
2026-07-12 - PCB v1.1
